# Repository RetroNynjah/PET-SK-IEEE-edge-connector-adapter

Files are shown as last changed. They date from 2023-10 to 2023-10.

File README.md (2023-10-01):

# PET SK IEEE-488 to edge connector adapter

Many accessories for the CBM PET such as SD2PET and PETdisk are desgined for models which have an edge connector for IEEE-BUS while the PET 8032-SK/8096-SK/200 has a standard IEEE-488 connector. That's a D-shaped connector which is sometimes called GPIB connector or Centronix connector.  
This cheap adapter converts from the standard IEEE-488 port on the SK models to a card edge so that standard PET accessories with edge connectors can be used.  

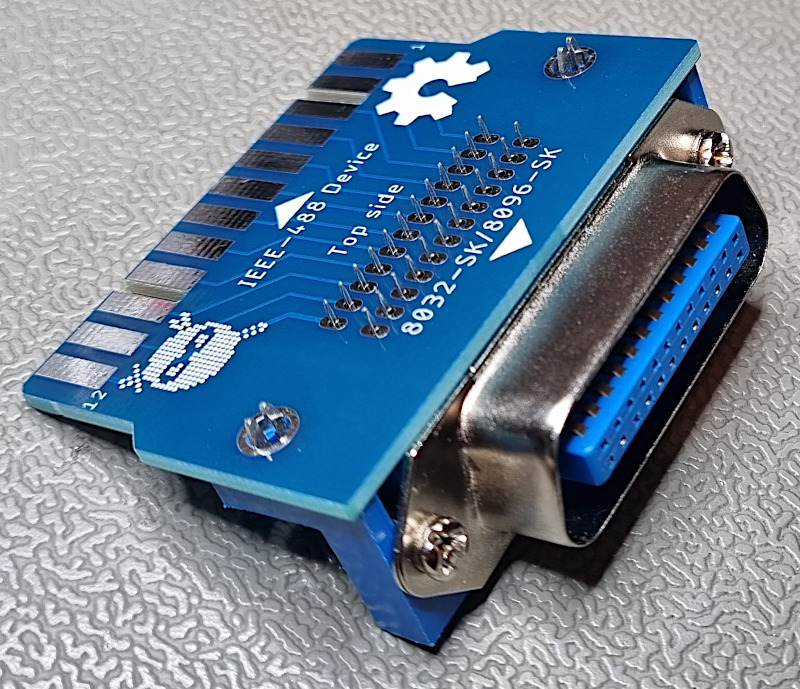
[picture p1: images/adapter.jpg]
Photo of adapter
<br/>

The adapter is very simple. It has straight connections from one side to the other. The part count can't get much lower as it only contains one component except for the PCB, a male right-angled IEEE-488 connector.  
Example of suitable connector: https://www.aliexpress.com/item/32795413098.html

| **Signal** | **GPIB** | **Edge** |
|:---:|:---:|:---:|
| DIO1 | 1 | 1 |
| DIO2 | 2 | 2 |
| DIO3 | 3 | 3 |
| DIO4 | 4 | 4 |
| EOI | 5 | 5 |
| DAV | 6 | 6 |
| NRFD | 7 | 7 |
| NDAC | 8 | 8 |
| IFC | 9 | 9 |
| SRQ | 10 | 10 |
| ATN | 11 | 11 |
| SHIELD | 12 | 12 |
| DIO5 | 13 | A |
| DIO6 | 14 | B |
| DIO7 | 15 | C |
| DIO8 | 16 | D |
| REN | 17 | E |
| GND | 18 | F |
| GND | 19 | H |
| GND | 20 | J |
| GND | 21 | K |
| GND | 22 | L |
| GND | 23 | M |
| GND | 24 | N |

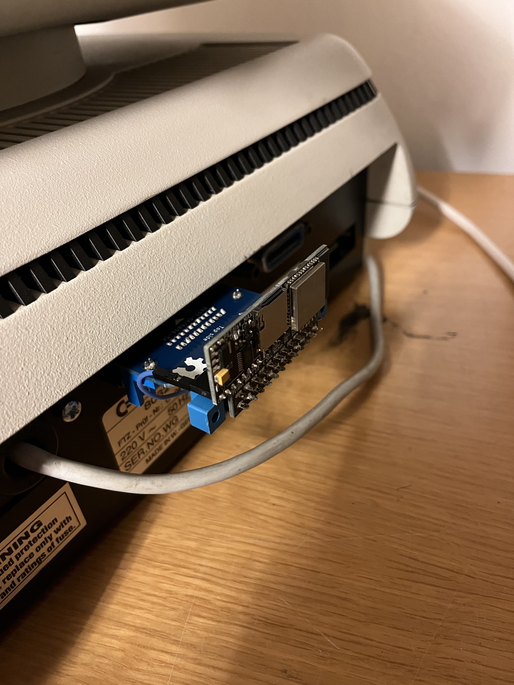
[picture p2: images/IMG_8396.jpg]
Photo of adapter installed
<br/>
PETdisk Max v2 installed in PET

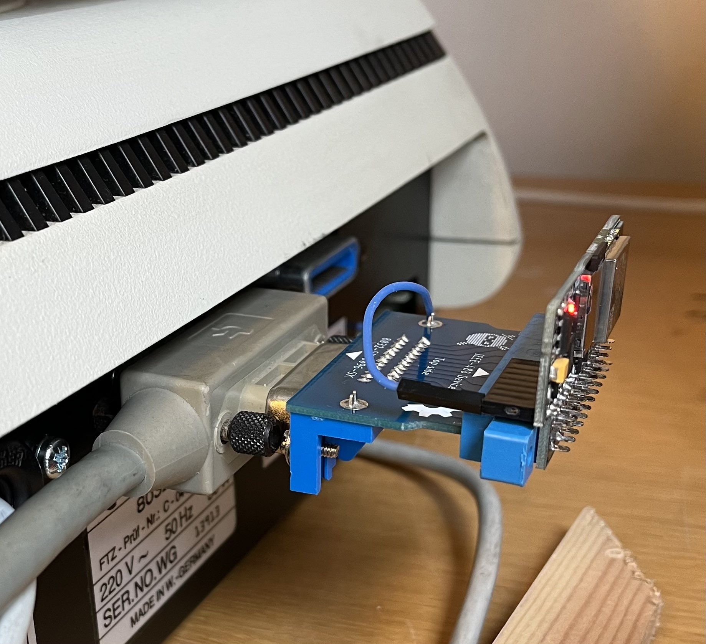
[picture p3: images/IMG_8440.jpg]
Photo of adapter installed together with floppy cable
<br/>
PETdisk Max v2 installed together with floppy drive in PET

Thanks to Jonas for the PETdisk Max v2 photos.

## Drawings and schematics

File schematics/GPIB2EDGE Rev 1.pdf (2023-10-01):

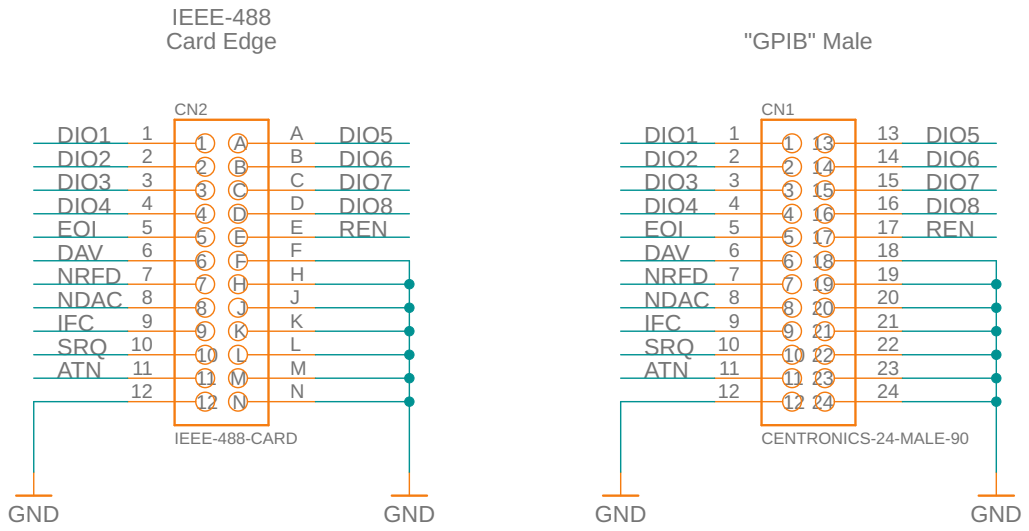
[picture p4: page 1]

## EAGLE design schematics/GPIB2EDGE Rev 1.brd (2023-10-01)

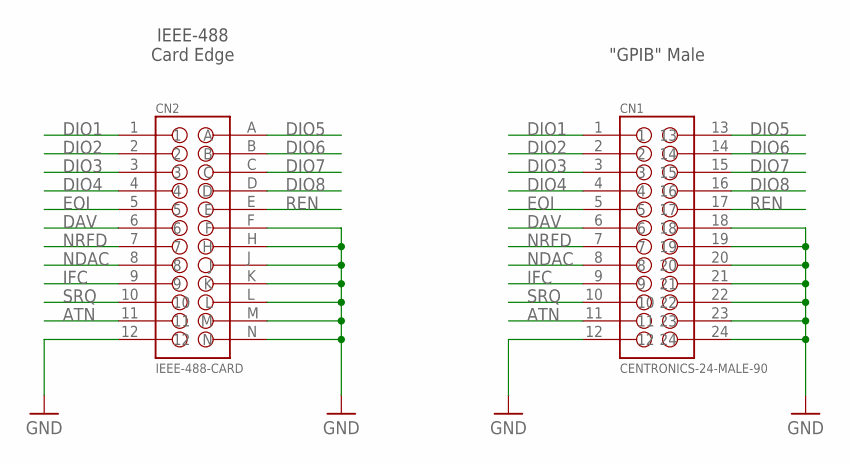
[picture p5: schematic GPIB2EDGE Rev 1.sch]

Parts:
CN1: CENTRONICS-24-MALE-90; CENTRONICS-24-M-90
CN2: IEEE-488-CARD; IEEE-488-EDGE-CARD

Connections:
ATN: CN1.11, CN2.11
DAV: CN1.6, CN2.6
DIO1: CN1.1, CN2.1
DIO2: CN1.2, CN2.2
DIO3: CN1.3, CN2.3
DIO4: CN1.4, CN2.4
DIO5: CN1.13, CN2.A
DIO6: CN1.14, CN2.B
DIO7: CN1.15, CN2.C
DIO8: CN1.16, CN2.D
EOI: CN1.5, CN2.5
GND: CN1.12, CN1.18, CN1.19, CN1.20, CN1.21, CN1.22, CN1.23, CN1.24, CN2.12, CN2.F, CN2.H, CN2.J, CN2.K, CN2.L, CN2.M, CN2.N
IFC: CN1.9, CN2.9
NDAC: CN1.8, CN2.8
NRFD: CN1.7, CN2.7
REN: CN1.17, CN2.E
SRQ: CN1.10, CN2.10

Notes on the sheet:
IEEE-488 Card Edge
"GPIB" Male

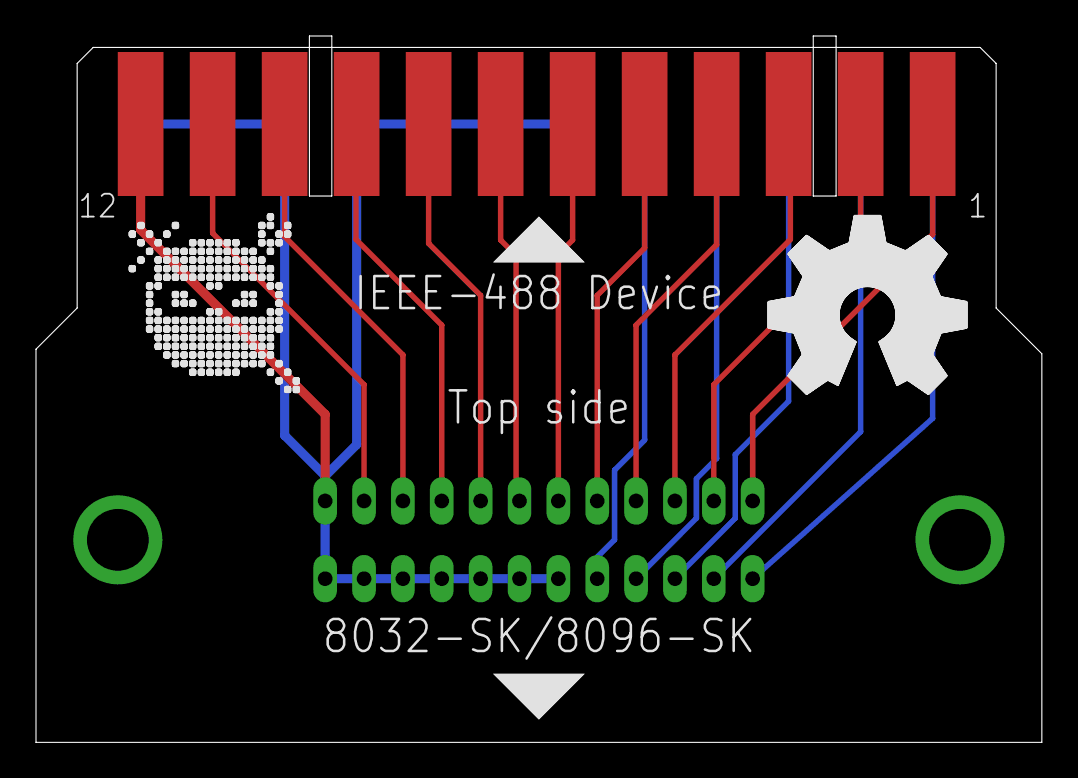
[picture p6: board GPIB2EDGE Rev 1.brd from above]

Board: 2 copper layers, 55.9 x 39.2 mm, 4 parts (1 on the bottom side), 17 nets.

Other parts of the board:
U$1: OSHW_NOTEXT_10MM
U$2: RETRONINJA_NOTEXT_10MM
